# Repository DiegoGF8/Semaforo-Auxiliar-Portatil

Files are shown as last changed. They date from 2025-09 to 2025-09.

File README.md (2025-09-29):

# Semaforo-Auxiliar-Portatil
**PROYECTO:** Sistema de Semáforo Auxiliar Portátil (PCB + Ensamble 3D)

## Descripción
Este repositorio contiene el diseño electrónico (OrCAD Capture CIS y OrCAD PCB Editor/Allegro), el ensamble mecánico de la PCB en 3D y las **salidas de fabricación** (Gerbers, taladros y pick & place) del sistema de semáforo auxiliar portátil.

- **Link directo al elemento PCB:** <https://cad.onshape.com/documents/21fef1b3eacda39c10852529/w/79fc7292a46ee710a65da7c9/e/ed5080d8918c1aaba1ee2e94>
  *Nota:* si no abre desde GitHub, copia y pega la URL en tu navegador o solicita acceso en Onshape.

**Nota:** El **BOM** y el **archivo de presupuesto** están en la carpeta **`Archivos de Manufactura/`**.

---

## Archivos de manufactura
Carpeta: [`Archivos de Manufactura/`](./Archivos%20de%20Manufactura/)

- **BOM y Presupuesto**
  - [BOM_PCB_SAP.xlsx](./Archivos%20de%20Manufactura/BOM_PCB_SAP.xlsx)
  - [Presupuesto_PCB_SAP.xlsx](./Archivos%20de%20Manufactura/Presupuesto_PCB_SAP.xlsx)

- **Gerbers (.art)**
  - [SAP_V11.SSTOP.art](./Archivos%20de%20Manufactura/SAP_V11.SSTOP.art)
  - [SAP_V110.SSBOT.art](./Archivos%20de%20Manufactura/SAP_V110.SSBOT.art)
  - [SAP_V111.DOUTLINE.art](./Archivos%20de%20Manufactura/SAP_V111.DOUTLINE.art)
  - [SAP_V12.SMTOP.art](./Archivos%20de%20Manufactura/SAP_V12.SMTOP.art)
  - [SAP_V13.SPTOP.art](./Archivos%20de%20Manufactura/SAP_V13.SPTOP.art)
  - [SAP_V14.TOP.art](./Archivos%20de%20Manufactura/SAP_V14.TOP.art)
  - [SAP_V15.INTERNAL1.art](./Archivos%20de%20Manufactura/SAP_V15.INTERNAL1.art)
  - [SAP_V16.INTERNAL2.art](./Archivos%20de%20Manufactura/SAP_V16.INTERNAL2.art)
  - [SAP_V17.BOTTOM.art](./Archivos%20de%20Manufactura/SAP_V17.BOTTOM.art)
  - [SAP_V18.SPBOT.art](./Archivos%20de%20Manufactura/SAP_V18.SPBOT.art)
  - [SAP_V19.SMBOT.art](./Archivos%20de%20Manufactura/SAP_V19.SMBOT.art)

- **Taladros**
  - [pcb_semaforo_aux1-1-4.drl](./Archivos%20de%20Manufactura/pcb_semaforo_aux1-1-4.drl)

- **Pick & Place**
  - [place_sap_2025.txt](./Archivos%20de%20Manufactura/place_sap_2025.txt)

---

## Archivos de diseño PCB
- [PCB_SEMAFORO_AUX.DSN](./PCB_SEMAFORO_AUX.DSN) — proyecto OrCAD Capture.
- [pcb_semaforo_aux.brd](./pcb_semaforo_aux.brd) — layout PCB (Allegro/OrCAD PCB Editor).
- [budget_energetico_final (3).pdf](./budget_energetico_final%20%283%29.pdf)
- [diagrama de bloques (2).png](./diagrama%20de%20bloques%20%282%29.png)

---

## Notas
- Para visualizar el ensamble 3D de la PCB, usa el enlace directo a Onshape indicado arriba.

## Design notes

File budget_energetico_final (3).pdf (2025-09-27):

## Universidad del Istmo

### Facultad de Ingeniería

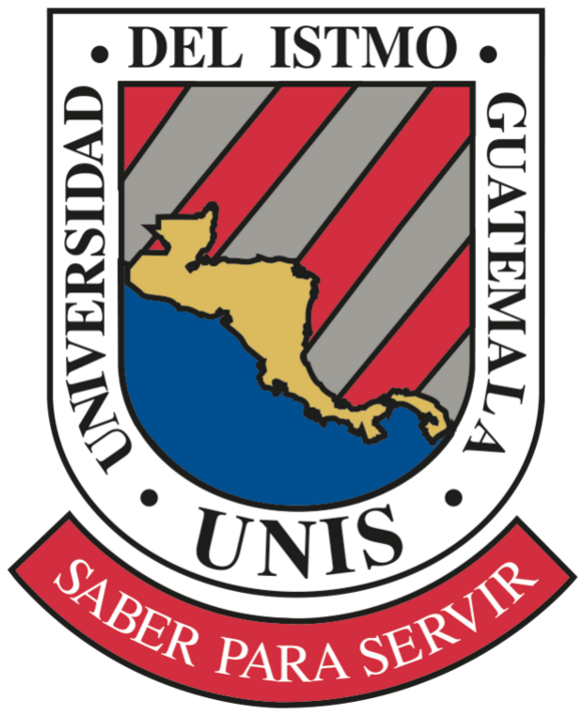
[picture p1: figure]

## Budget Energético

Curso: Trabajo de graduación Nombre: Diego José Girón Figueroa Fecha: septiembre de 2025

## Resumen de escenarios

Modo de operación: 6 h continuas por día.

Conversión 12→5 V: buck con η ≈ 90.00 %.

Batería: 12.8 V . DoD asumida: 80.00 %.

Solar: HSP ≈ 5 (Guatemala), eficiencia global del sistema ηsistema ≈ 75.00 %.

Margen de diseño: +25.00 % sobre la energía de 6 h.

## 1. Inventario de cargas: rail 5 V (vía buck desde 12 V)

Carga | V | Imin | Itíp | Ipico | Pmin | Ptíp | Ppico
(V) (A) | (A) | (A) | (W) | (W) (W)
Orange Pi Zero 3 | 5 | 0.50 0.60 | 1.00 | 2.50 | 3.00 | 5.00
Cámara USB | 5 | 0.10 0.20 | 0.50 | 0.50 | 1.00 | 2.50
Módulo USB LoRa | 5 | 0.02 0.05 | 0.20 | 0.10 | 0.25 | 1.00
Subtotal 5 V | 3.10 4.25 8.50

Equivalente a 12 V (entrada del buck, η = 90 %):

P

min
in,12V =

3.10
0.90
= 3.44W, | Ptíp
| | | in,12V =

4.25
0.90
= 4.72W, | Ppico
| | | | | | | in,12V =

8.50
0.90

= 9.44W.

## 2. Inventario de cargas: rail 12 V (directo a batería)

Carga | V | Imin | Itíp | Ipico | Pmin | Ptíp | Ppico
(V) (A) | (A) | (A) | (W) | (W) (W)
Sirena 12 V | 12 | 0.00 0.15 | 0.30 | 0.00 | 1.80 | 3.60
Estrobo LED | 12 | 0.30 0.60 | 1.00 | 3.60 | 7.20 | 12.00
Subtotal 12 V | 3.60 9.00 15.60

## 3. Totales por escenario y dimensionamiento

### Potencia y energía

Mínimo | Típico | Pico
Potencia total Ptot (W) | P
| | | min
in,12V + 3.60 = 7.04 | 4.72 + 9.00 = 13.72 | 9.44 + 15.60 = 25.04
Energía 6 h E6h (Wh) | 7.04 × 6 = 42.24 | 13.72 × 6 = 82.32 | 25.04 × 6 = 150.24
Energía con +25 % E

′
(Wh) | 52.80 | 102.90 | 187.80

### Batería (12.8 V, DoD = 80 %)

Creq =

E

′
Vnom · DoD

=

E

′
12.8 × 0.80

=

E

′
10.24

(Ah)

1

Mínimo | Típico | Pico

Capacidad requerida Creq (Ah) 52.80

10.24 = 5.16 | 102.90
| 10.24 = 10.06 | 187.80 10.24 = 18.34

### Panel solar (HSP = 5, ηsistema = 75 %)

PPV,min =

E

′

HSP · ηsistema

=

E

′
5 × 0.75

=

E

′
3.75

(W)

Mínimo | Típico | Pico

Potencia de panel requerida (W) 52.80
3.75 = 14.08 | 102.90
3.75 | = 27.44 | 187.80
3.75 | = 50.08

## 4. Selección propuesta

Batería: 12.8 V 20 Ah (cubre pico con holgura y mejora vida útil).

Panel: 100W a 12 V (supera sobradamente el escenario pico diario considerando pérdidas y nubes).

Controlador: PWM 10 A compatible.

Buck 12→5 V: ≥5.00 A.

Fusibles orientativos: principal batería 20.00–30.00 A; buck 5.00–10.00 A; sirena 5.00–10.00 A; estrobo 10.00–15.00 A.

## 5. Fórmulas

P = V · I, Pin =

Pout
η
, | E = P · t,
Creq (Ah) = | E

′
(Wh)
Vnom (V) · DoD
, | PPV,min =

E

′

HSP · ηsistema

2

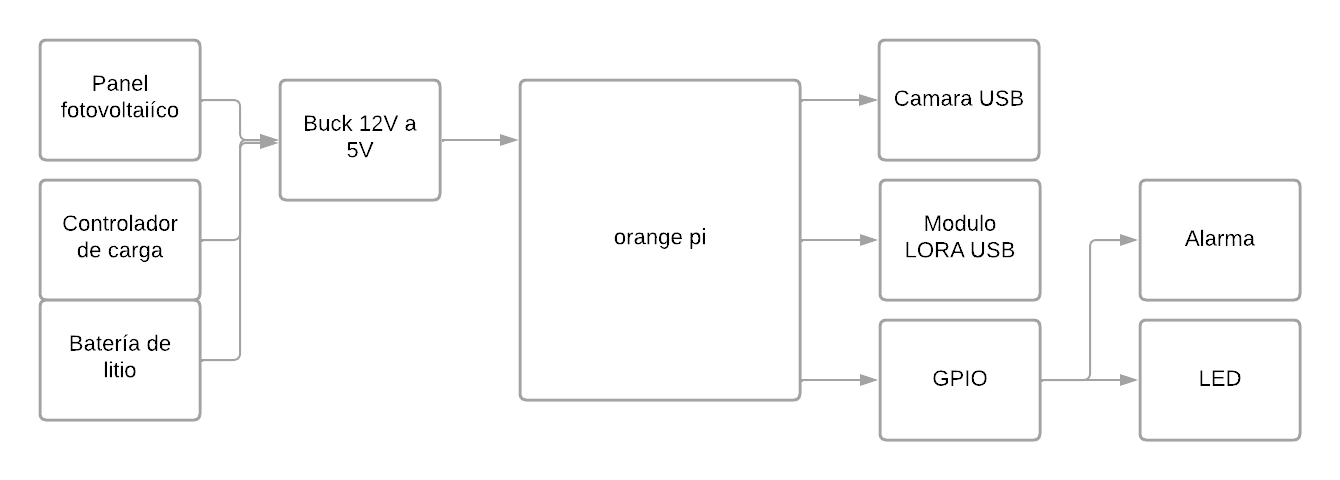
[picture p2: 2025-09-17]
diagrama de bloques (2).png

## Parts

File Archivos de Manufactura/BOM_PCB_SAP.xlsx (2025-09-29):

Cantidad | Componente | Modelo | Capacidad | Fabricante | JLCPCB Part Number
1 | Regulador buck DC-DC | LM2678S-5.0 | 12 V → 5 V / 5 A | Texas Instruments | C3167469
1 | Inductor de potencia SMD | LQH66SN220MD3L | 22 µH | Murata | C113092
1 | Diodo Schottky potencia | 6TQ045S | 45 V / ≥6 A | Taiwan Semiconductor | C145462
2 | Relé SPDT 12 V bobina | SRD-12VDC-SL-C | 12 V coil / 10 A contactos | Songle | C30431
2 | MOSFET canal-N, logic-level | IRLML6344TRPBF | 30 V, SOT-23, | Infineon | C53550
2 | Diodo de protección | 1N5819 | 30 V, 1 A | STMicroelectronics | C2474
1 | Cabecera 2×13 pines (GPIO Orange Pi) | SSQ-113-01-G-S-LL | Paso 2.54 mm, 2×13 | Samtec | C6235668
2 | Conector USB-A hembra THT RA | USB-A1HSB6 | USB 2.0 | On Shore Technology Inc. | C3197701
4 | Terminal block 2 pines 5.08 mm | TB002-500-02BE | ≤ 300 V / ≥ 10 A | Same Sky (Formerly CUI Devices) | C2757858
7 | Resistencias | RC0402JR-070RL | 0 Ω | Yageo | C60485
4 | Resistencias | RC0402JR-071ML | 1 MΩ | Yageo | C93949
3 | Capacitores electrolíticos | EEA-GA1H150 | 15 uF | Panasonic Electronic Components | C1585476
2 | Capacitores electrolíticos | 860020675019 | 180 Uf | Würth Elektronik | C1585013
1 | Capacitores no polarizados | 06035C103MAZ2A | 0.01 uF | KYOCERA AVX | C1524
4 | Capacitores no polarizados | GRM155R61H474KE11D | 0.47 uF | Murata Electronics | C437527
2 | Resistencias | RC0603FR-07470RL | 470 Ω | Yageo | C114669
2 | Resistencias | RC0402FR-074K7L | 4.7 KΩ | Yageo | C105871
1 | Orange Pi Zero 3 | Orange Pi Zero 3
1 | FUSE HLDR BLADE 32V 20A IN LINE | F3209-ND | Fusible | Littelfuse/Commercial Vehicle Products

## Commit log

2025-09-17 Diagrama de bloques
2025-09-20 Create Gerber
2025-09-20 Create BOM
